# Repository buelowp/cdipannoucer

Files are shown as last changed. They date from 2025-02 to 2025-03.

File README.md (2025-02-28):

# Cobalt Digigal IP turnout control state announcer
The goal of this project is to provide a simple mechanism to report the realtime state of a Cobal Digital IP turnout control motor to loconet. For brevity, Cobalt Digital IP is reduced to CDIP in my work.

## Design
The Cobalt motor is really nice, it's a self contained DCC design and is reasonably robust. Not the quietest, but it works, and it works well with Digitrax and JMRI. However, because it's DCC only, JMRI has no mechanism for requesting state from the motor. This means, at startup, or if something outside of Loconet changes the turnout state, JMRI does not know that it happened. I like it when I see my layout in JMRI in the correct state. I have a 4 turnout cross over and two turnouts which gate reverse loops which are automated

So, basically, I chose this as a low impact HW/SW project I could do to solve the problem. I'm learning how to do HW as a long term software engineer by trade, and enjoy doing small projects with MCU's. This may not be very useful to very many people, but it's fun and I'm looking forward to using it on my layout which has about 30 turnouts in a 19'x19' snaking layout.

This will not do loconet forwarding, and you can't daisy chain. I started to think for the cost, it's pry just smarter to use a UP7 without the faceplate which gives you 4 reliable ports for ~16USD. While adding the HW here would have been cheaper, the cost and complexity made it less interesting to me. I may put it back in later as I get better a loconet circuitry. I removed the daisy chain option, even though that's effectively free, as you can't infinitely chain non boosted devices together, and I didn't want to keep track of how many were connected.

This design makes use of Seeed Studio XIAO modules. I love these things. They are pretty cheap overall, tiny, and you can swap different modules on the same carrier. So, my design uses the Pico MCU because I don't want to include WiFi in my design. My basement layout is pretty far from the nearest router, and I don't want to suck up a lot of the router's attention for these when turned on. However, without changing the hardware, or changing the board size, anyone could use the ESP32 if they choose to. The benefit there might be MQTT and adding a webserver to assign DCC addresses without recompiling the firmware.

While not yet coded up, my mechanism for knowing when to send a startup message will be based on the first Loconet traffic the board sees. As this can be DCC powered, it can also be DC powered, so triggering on when we start to see traffic would be the most beneficial in all cases.

## Requirements
* Provide Loconet messages for turnout state changes as they happen
* Provide a loconet message indicating turnout state on DCC power up
* Handle four turnouts on one board
* Run with either an ESP32 or RPi Pico
* Not require more than 8 GPIO (this one currently only uses 7, three are just there not doing much)
* Wide input voltage range
* Allow for direct connection of indicator LEDs for the turnout.
    * This allows to wire up signals as an example, without the need for extra diodes/resistors along the wire run.

### What it doesn't currently do
* Will not switch the turnout via a Loconet message
* Does not have a second Loconet port for daisy chain

## KiCad design
This is a work in progress. What I've got posted now is version 2, not yet ordered.

I built a first board based solely on a few simple schematic facts hoping they all sort of would just work. This did allow me to test the GPIO portion of the design and validate my assumptions were correct. However, version 1, which is not in git unforunately, did not work for Loconet traffic. I don't know why, but I did make a mistake in the pin assigments for the second Serial port on the XIAO Pico module. I did jumper it, but it still doesn't work. I also didn't add test points, so it's not possible for me at home to use a scope to figure out what's going on. All of those facts are fixed in the current version.

Recently, I also added the ability to use DCC for power. However, I couldn't find a way to combine the two DCC connectors at that point, so you always need a DCC input for the IO, but if you want to power via DCC, then you simply plug a DCC bus into the power connection. For this reason, that connection is no longer polarized, and it doesn't matter which way you wire it.

I also added 3 pins connected to D8, D9, and D10 in Arduino land. They have both Ground and Power pins to go with, so you can use them however you feel the urge. I would limit any GPIO access to 30ma total though, as you have 500ma from the board, but roughly 200ma is already consumed.

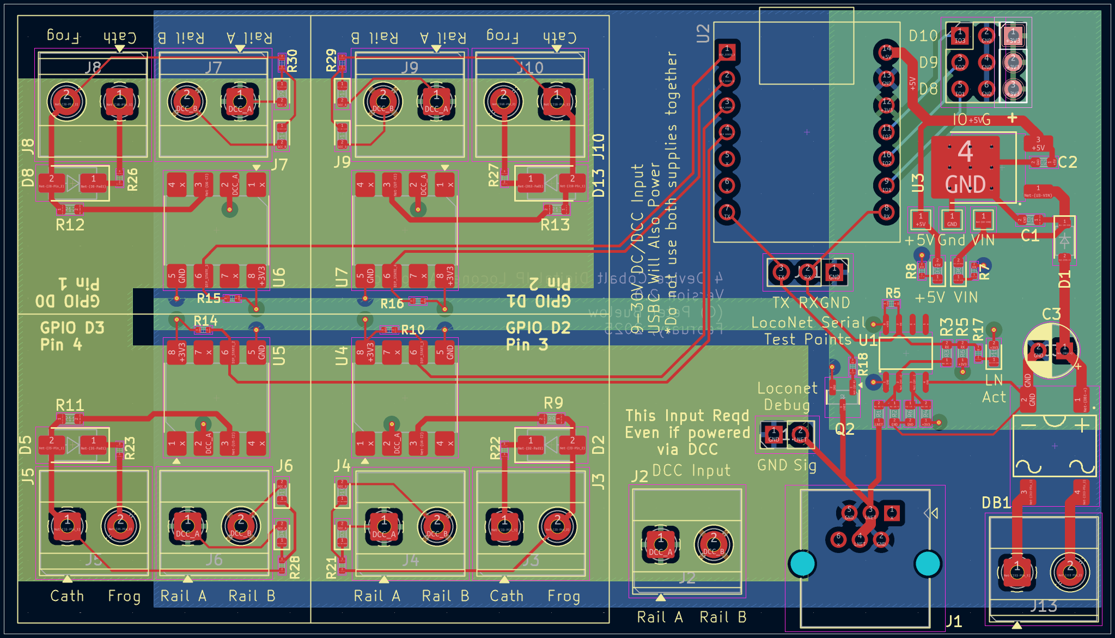
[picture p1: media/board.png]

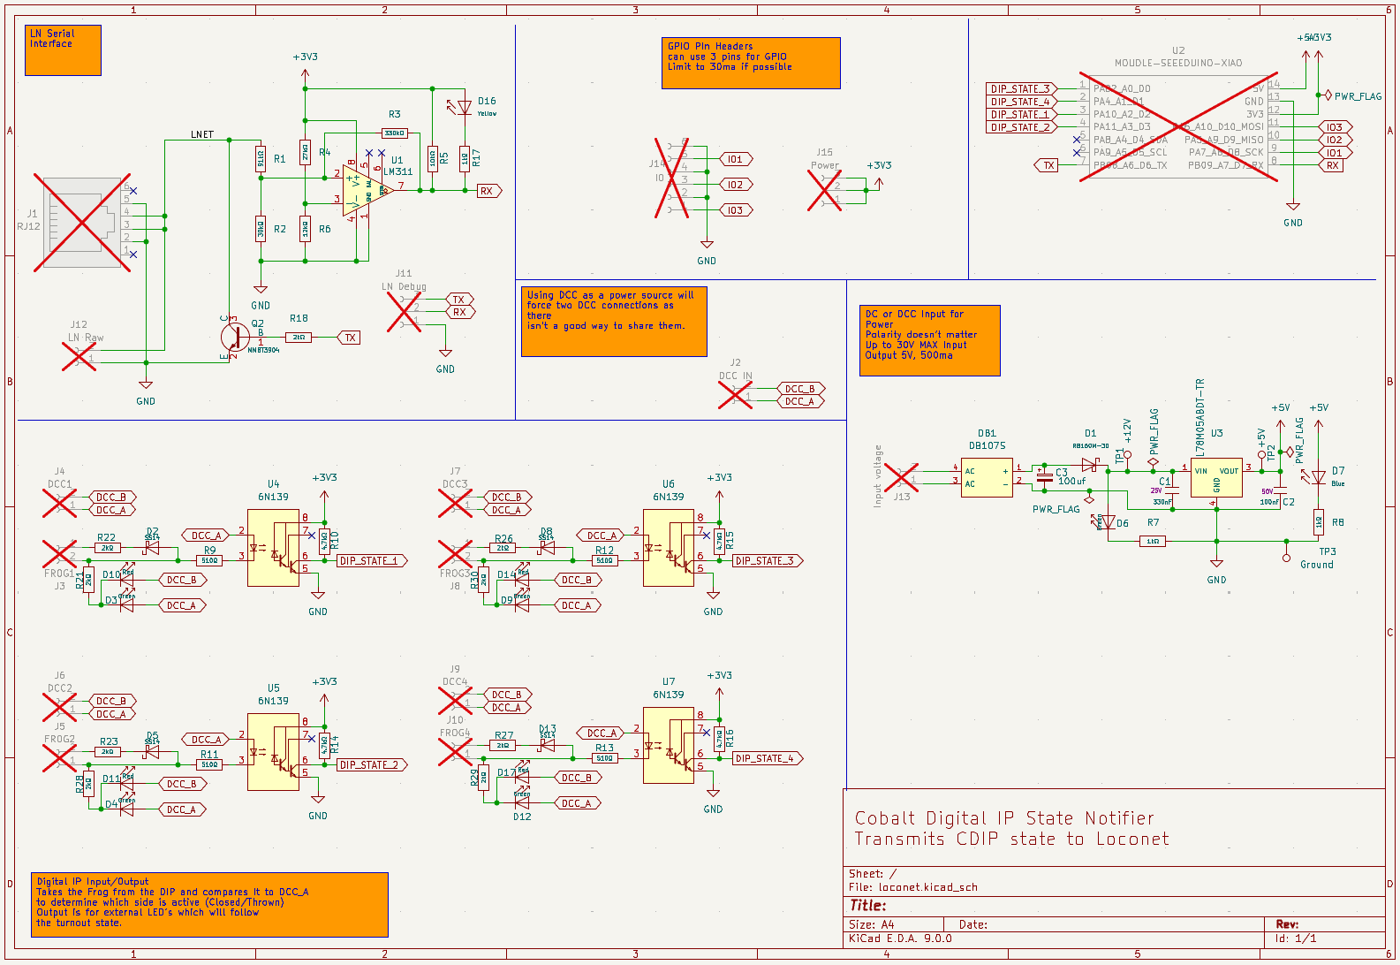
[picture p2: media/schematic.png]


## KiCad notes
This design makes use of JLCPCB to source and order. The parts are identified in the BOM, and the parts that can't be assembled by JLCPCB are marked as such (the red X). I used a plugin to get the parts from

https://github.com/CDFER/JLCPCB-Kicad-Library

Which cannot at this time be installed automatically. Follow the directions on the README.

I also use the JLCPCB Fab extension which can be installed directly from the Extensions dialog.

# Notes
* The orientation of the DCC inputs into the Digital IP does matter. I assume for this device that DCC Rail A as labeled coming out of a Digitrax command station is the outer most pin 1 in the diagram below. If you reverse and put DCC Rail B into that slot, you either have to reverse Rail A and B inputs for the DCC Input terminal or update the code to account for the direction messages being backwards. Note, if you reverse using DCC address 197, you must also reverse the direction. This can be done by setting the CDIP inverted boolean to true.
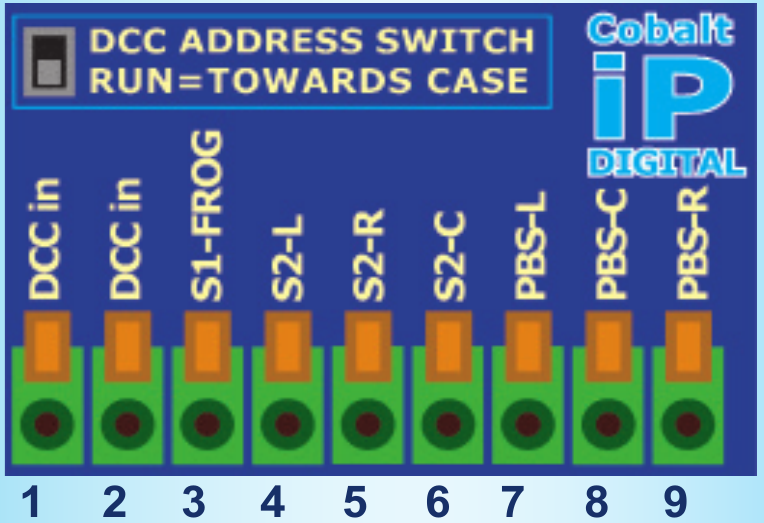
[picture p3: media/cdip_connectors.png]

* This is DC only, but takes up to 30V as input. The reason for this is that I have a 15V DC power bus running with the DCC bus to power some of the Digitrax devices in use (mostly PM74's). For the length of those conductors, even at 16Ga, you get some voltage drop and this should allow the boards to not worry about that.

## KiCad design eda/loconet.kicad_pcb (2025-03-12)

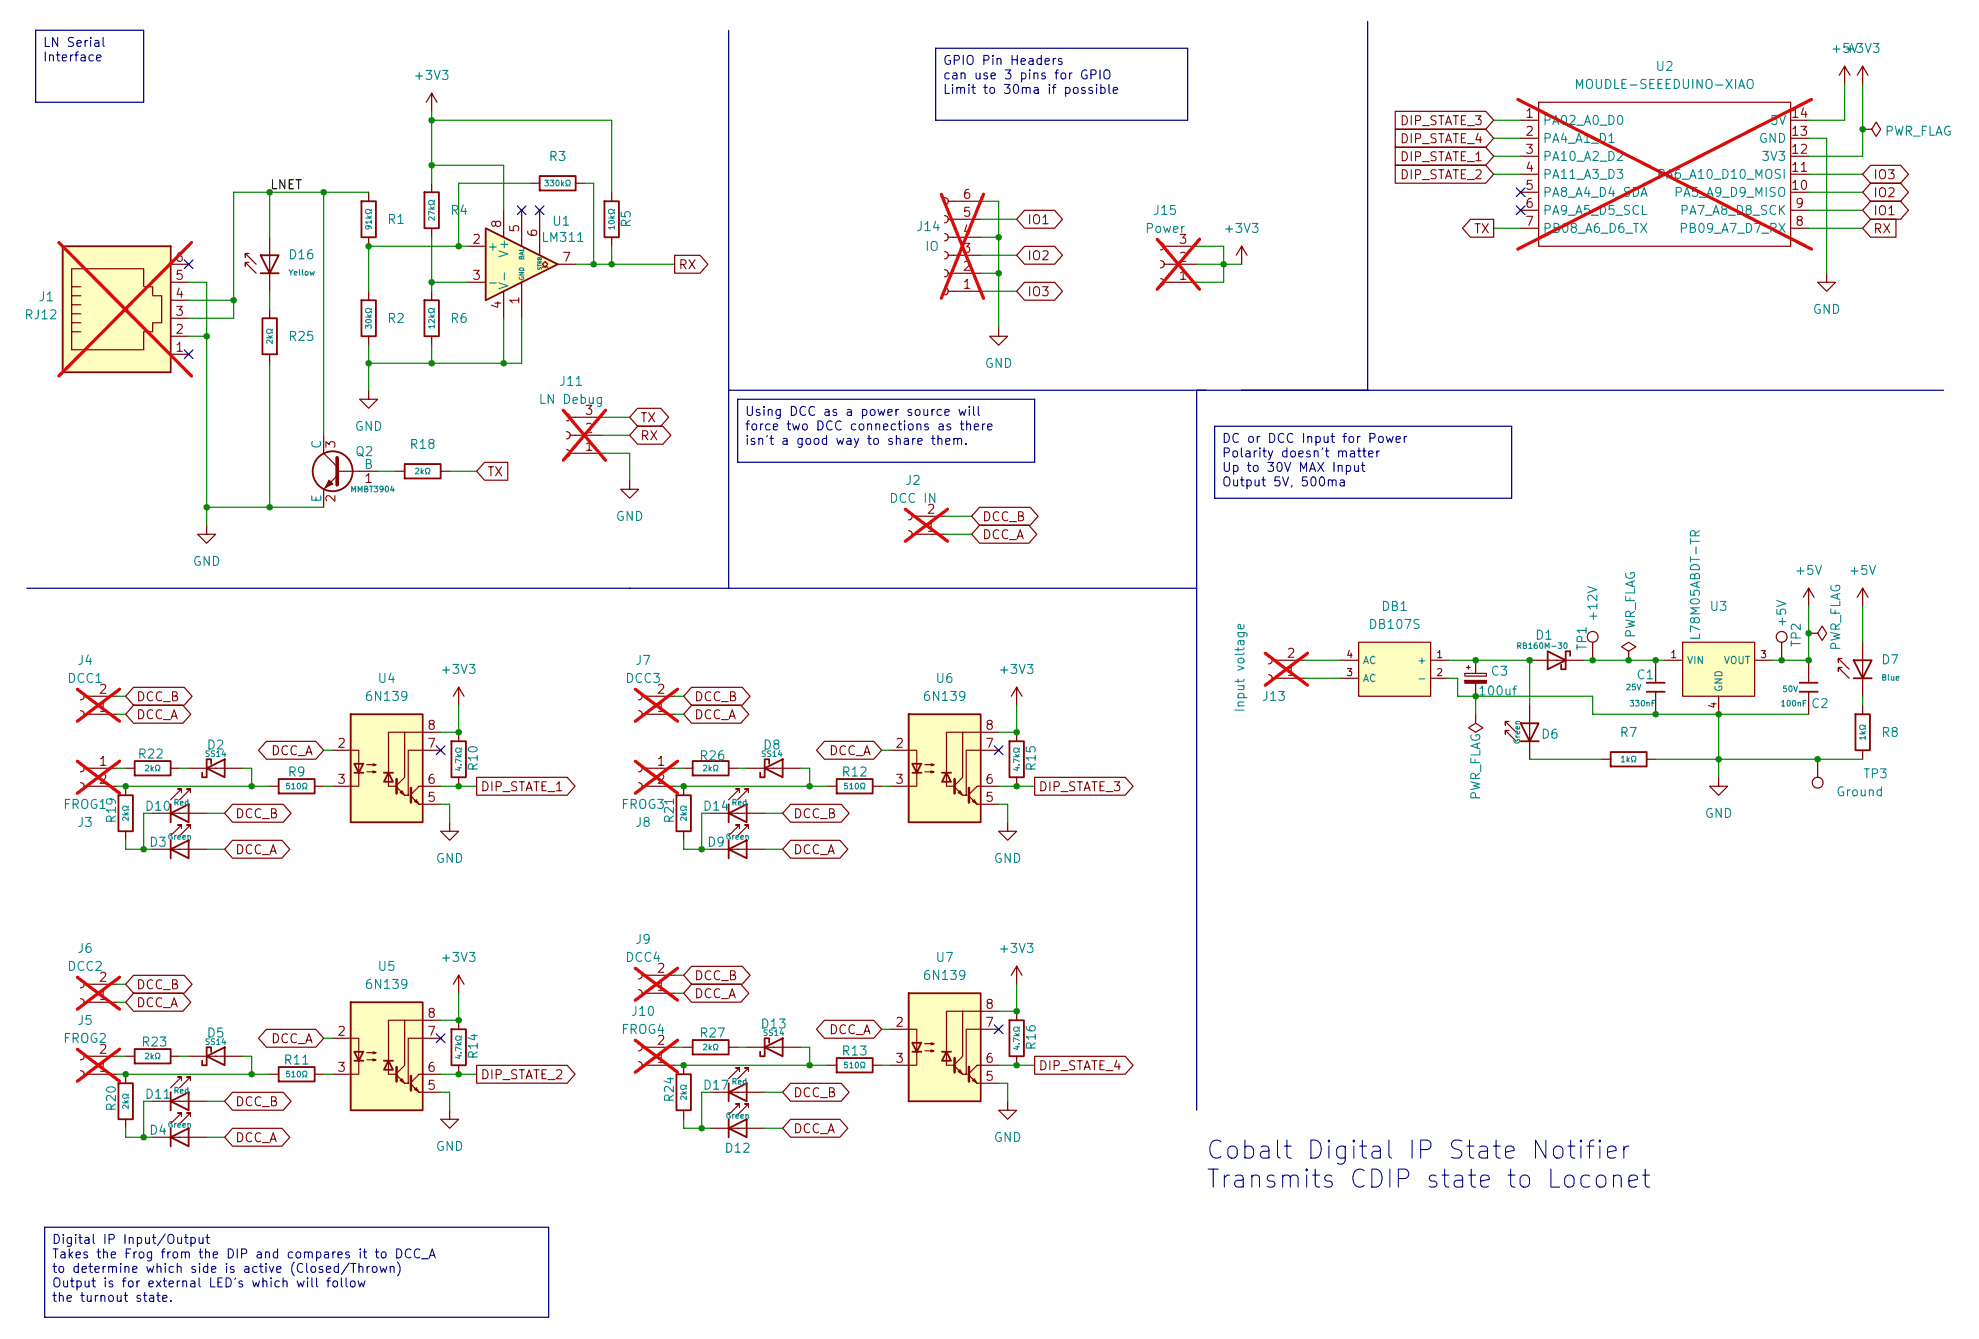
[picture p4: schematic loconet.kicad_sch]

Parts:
C1: 330nF; C_0603; Voltage Rated 25V; Tolerance ±10%; Part 0603B334K250NT; LCSC C1615
C2: 100nF; C_0603; Voltage Rated 50V; Tolerance ±10%; Part CC0603KRX7R9BB104; LCSC C14663
C3: 100uf; CP_Radial_D5.0mm_P2.50mm
D1: RB160M-30; D_SOD-123; Forward Voltage (Vf@If) 480mV@1A; Reverse Voltage (Vr) 30V; Part RB160M-30; LCSC C7502715
D2, D5, D8, D13: SS14; D_SMA; Forward Voltage (Vf@If) 550mV@1A; Reverse Voltage (Vr) 40V; Part SS14; LCSC C2480
D3, D4, D6, D9, D12: Green; D_0603; Part 19-217/GHC-YR1S2/6T; LCSC C2986059
D7: Blue; D_0603; Part 19-217/BHC-ZL1M2RY/6T; LCSC C2986058
D10, D11, D14, D17: Red; D_0603; Part KT-0603R; LCSC C2286
D16: Yellow; D_0603; Part 19-213/Y2C-CQ2R2L/3T(CY); LCSC C72038
DB1: DB107S; DBS_L8.2-W6.4-P5.10-LS10.0-BL; Reverse Voltage (Vr) 1kV; Forward Voltage (Vf@If) 1.1V@1A; Part DB107S; LCSC C5377
J1: RJ12; RJ25_Wayconn_MJEA-660X1_Horizontal; not fitted
J2: DCC IN; TerminalBlock_Phoenix_MKDS-1,5-2-5.08_1x02_P5.08mm_Horizont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; not fitted
J3: FROG1; TerminalBlock_Phoenix_MKDS-1,5-2-5.08_1x02_P5.08mm_Horizont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; not fitted
J4: DCC1; TerminalBlock_Phoenix_MKDS-1,5-2-5.08_1x02_P5.08mm_Horizont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; not fitted
J5: FROG2; TerminalBlock_Phoenix_MKDS-1,5-2-5.08_1x02_P5.08mm_Horizont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; not fitted
J6: DCC2; TerminalBlock_Phoenix_MKDS-1,5-2-5.08_1x02_P5.08mm_Horizont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; not fitted
J7: DCC3; TerminalBlock_Phoenix_MKDS-1,5-2-5.08_1x02_P5.08mm_Horizont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; not fitted
J8: FROG3; TerminalBlock_Phoenix_MKDS-1,5-2-5.08_1x02_P5.08mm_Horizont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; not fitted
J9: DCC4; TerminalBlock_Phoenix_MKDS-1,5-2-5.08_1x02_P5.08mm_Horizont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; not fitted
J10: FROG4; TerminalBlock_Phoenix_MKDS-1,5-2-5.08_1x02_P5.08mm_Horizont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; not fitted
J11: LN Debug; PinHeader_1x03_P2.54mm_Vertical; not fitted
J13: Input voltage; TerminalBlock_Phoenix_MKDS-1,5-2-5.08_1x02_P5.08mm_Horizont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; not fitted
J14: IO; PinHeader_2x03_P2.54mm_Vertical; not fitted
J15: Power; PinHeader_1x03_P2.54mm_Vertical; not fitted
Q2: MMBT3904; Q_SOT-23; Part MMBT3904; LCSC C7420353
R1: 91kΩ; R_0603; Overload Voltage (Max) 75V; Tolerance ±1%; Part 0603WAF9102T5E; LCSC C23265
R2: 30kΩ; R_0603; Overload Voltage (Max) 75V; Tolerance ±1%; Part 0603WAF3002T5E; LCSC C22984
R3: 330kΩ; R_0603; Overload Voltage (Max) 75V; Tolerance ±1%; Part 0603WAF3303T5E; LCSC C23137
R4: 27kΩ; R_0603; Overload Voltage (Max) 75V; Tolerance ±1%; Part 0603WAF2702T5E; LCSC C22967
R5: 10kΩ; R_0603; Overload Voltage (Max) 75V; Tolerance ±1%; Part 0603WAF1002T5E; LCSC C25804
R6: 12kΩ; R_0603; Overload Voltage (Max) 75V; Tolerance ±1%; Part 0603WAF1202T5E; LCSC C22790
R7, R8: 1kΩ; R_0402; Overload Voltage (Max) 50V; Tolerance ±1%; Part 0402WGF1001TCE; LCSC C11702
R9, R11, R12, R13: 510Ω; R_0603; Overload Voltage (Max) 75V; Tolerance ±1%; Part 0603WAF5100T5E; LCSC C23193
R10, R14, R15, R16: 4.7kΩ; R_0402; Overload Voltage (Max) 50V; Tolerance ±1%; Part 0402WGF4701TCE; LCSC C25900
R18, R22, R23, R25, R26, R27: 2kΩ; R_0402; Overload Voltage (Max) 50V; Tolerance ±1%; Part 0402WGF2001TCE; LCSC C4109
R19, R20, R21, R24: 2kΩ; R_0805; Overload Voltage (Max) 150V; Tolerance ±1%; Part 0805W8F2001T5E; LCSC C17604
TP1: +12V; TestPoint_Pad_1.5x1.5mm
TP2: +5V; TestPoint_Pad_1.5x1.5mm
TP3: Ground; TestPoint_Pad_1.5x1.5mm
U1: LM311; SOIC-8_L4.9-W3.9-P1.27-LS6.0-BL; LCSC C231850
U2: MOUDLE-SEEEDUINO-XIAO; MOUDLE14P-2.54-21X17.8MM; not fitted
U3: L78M05ABDT-TR; TO-252-2_L6.5-W6.1-P4.58-LS10.0-TL; Output Voltage 5V; Part L78M05ABDT-TR; LCSC C58069
U4, U5, U6, U7: 6N139; SOP-8_6.605x9.655mm_P2.54mm; LCSC C42186

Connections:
+3V3: J15.1, J15.2, J15.3, R4.1, R5.1, R10.1, R14.1, R15.1, R16.1, U1.8 (V+), U2.12 (3V3), U4.8 (VCC), U5.8 (VCC), U6.8 (VCC), U7.8 (VCC); also elsewhere on the board
+5V: C2.1, D7.2, TP2.1, U2.14 (5V), U3.3 (VOUT)
/LNET: D16.2, J1.3, J1.4, Q2.3 (C), R1.1
DCC_A: D3.2, D4.2, D9.2, D12.2, J2.1, J4.1, J6.1, J7.1, J9.1, U4.2 (C1), U5.2 (C1), U6.2 (C1), U7.2 (C1)
DCC_B: D10.2, D11.2, D14.2, D17.2, J2.2, J4.2, J6.2, J7.2, J9.2
DIP_STATE_1: R10.2, U2.3 (PA10_A2_D2), U4.6 (VO2)
DIP_STATE_2: R14.2, U2.4 (PA11_A3_D3), U5.6 (VO2)
DIP_STATE_3: R15.2, U2.1 (PA02_A0_D0), U6.6 (VO2)
DIP_STATE_4: R16.2, U2.2 (PA4_A1_D1), U7.6 (VO2)
GND: C1.2, C2.2, C3.2, DB1.2 (-), J1.2, J1.5, J11.1, J14.2, J14.4, J14.6, Q2.2 (E), R2.2, R6.2, R7.2, R8.2, R25.1, TP3.1, U1.1 (GND), U1.4 (V-), U2.13 (GND), U3.4 (GND), U4.5 (GND), U5.5 (GND), U6.5 (GND), U7.5 (GND)
IO1: J14.5, U2.9 (PA7_A8_D8_SCK)
IO2: J14.3, U2.10 (PA5_A9_D9_MISO)
IO3: J14.1, U2.11 (PA6_A10_D10_MOSI)
unnamed: D2.1, R22.2
unnamed: D5.1, R23.2
unnamed: D6.1, R7.1
unnamed: D7.1, R8.1
unnamed: D8.1, R26.2
unnamed: D3.1, D10.1, R19.2
unnamed: D4.1, D11.1, R20.2
unnamed: D12.1, D17.1, R24.2
unnamed: D13.1, R27.2
unnamed: D9.1, D14.1, R21.2
unnamed: D16.1, R25.2
unnamed: C3.1, D1.2, D6.2, DB1.1 (+)
unnamed: J3.1, R22.1
unnamed: D2.2, J3.2, R9.1, R19.1
unnamed: D5.2, J5.1, R11.1, R20.1
unnamed: J5.2, R23.1
unnamed: J8.1, R26.1
unnamed: D8.2, J8.2, R12.1, R21.1
unnamed: D13.2, J10.1, R13.1, R24.1
unnamed: J10.2, R27.1
unnamed: DB1.3 (AC), J13.1
unnamed: DB1.4 (AC), J13.2
unnamed: Q2.1 (B), R18.1
unnamed: R1.2, R2.1, R3.1, U1.2 (+)
unnamed: R4.2, R6.1, U1.3 (-)
unnamed: C1.1, D1.1, TP1.1, U3.1 (VIN)
unnamed: R9.2, U4.3 (C2)
unnamed: R11.2, U5.3 (C2)
unnamed: R12.2, U6.3 (C2)
unnamed: R13.2, U7.3 (C2)
RX: J11.2, R3.2, R5.2, U1.7, U2.8 (PB09_A7_D7_RX); also elsewhere on the board
TX: J11.3, R18.2, U2.7 (PB08_A6_D6_TX)

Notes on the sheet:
Cobalt Digital IP State Notifier Transmits CDIP state to Loconet
DC or DCC Input for Power Polarity doesn't matter Up to 30V MAX Input Output 5V, 500ma
Digital IP Input/Output Takes the Frog from the DIP and compares it to DCC_A to determine which side is active (Closed/Thrown) Output is for external LED's which will follow the turnout state.
GPIO Pin Headers can use 3 pins for GPIO Limit to 30ma if possible
LN Serial Interface
Using DCC as a power source will force two DCC connections as there isn't a good way to share them.

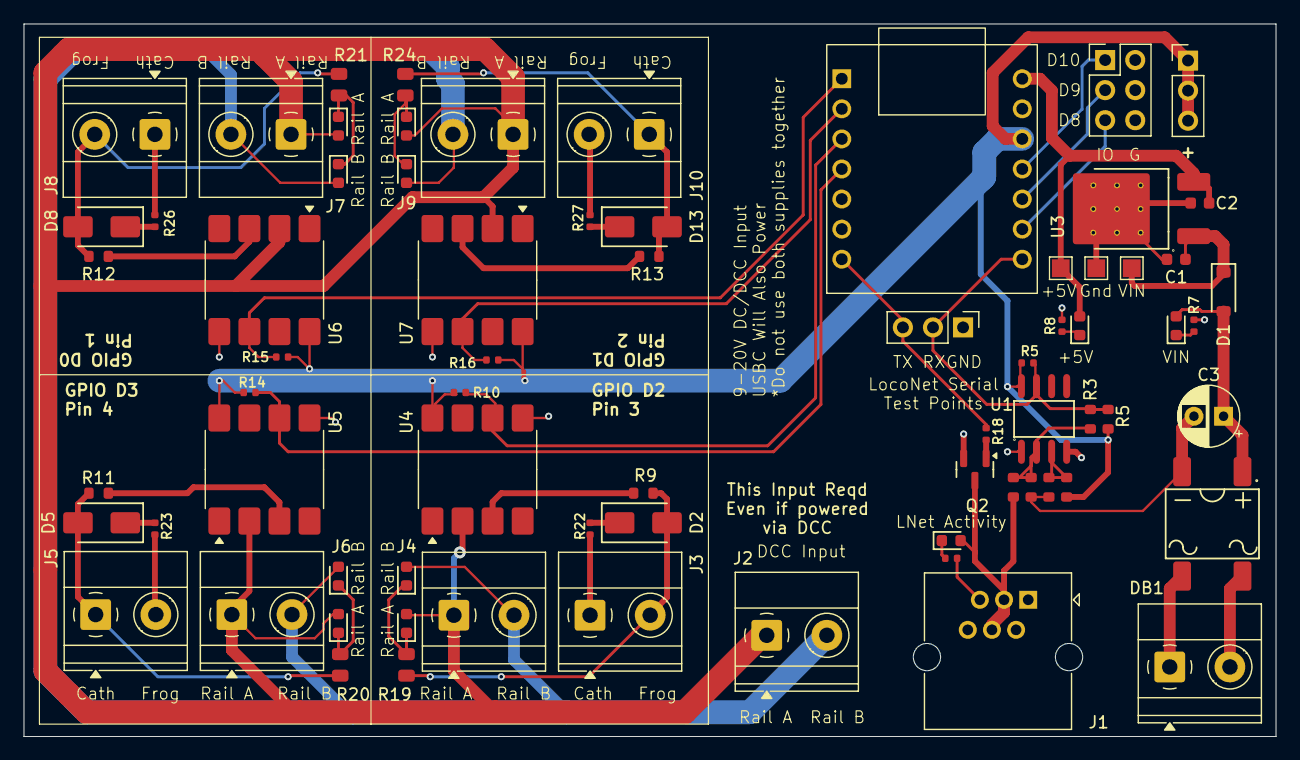
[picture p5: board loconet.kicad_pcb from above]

Board: 2 copper layers, 105.7 x 60.2 mm, 72 parts (0 on the bottom side), 45 nets.

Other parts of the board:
R5#2: 10kΩ; R_0603

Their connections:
+3V3: R5#2.1; also elsewhere on the board
RX: R5#2.2; also elsewhere on the board

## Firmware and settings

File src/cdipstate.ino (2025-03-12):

/*
MIT License

Copyright (c) 2025 Peter Buelow

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
THE SOFTWARE IS PROVIDED "AS IS", WITHOUT WARRANTY OF ANY KIND, EXPRESS OR
IMPLIED, INCLUDING BUT NOT LIMITED TO THE WARRANTIES OF MERCHANTABILITY,
FITNESS FOR A PARTICULAR PURPOSE AND NONINFRINGEMENT. IN NO EVENT SHALL THE
AUTHORS OR COPYRIGHT HOLDERS BE LIABLE FOR ANY CLAIM, DAMAGES OR OTHER
LIABILITY, WHETHER IN AN ACTION OF CONTRACT, TORT OR OTHERWISE, ARISING FROM,
OUT OF OR IN CONNECTION WITH THE SOFTWARE OR THE USE OR OTHER DEALINGS IN THE
SOFTWARE.
*/
#include <LocoNetStreamRP2040.h>
#include "pico/stdlib.h"

#include "cdip.h"

#define LOCONET_PIN_RX  PIN_SERIAL1_RX
#define LOCONET_PIN_TX  PIN_SERIAL1_TX

#define LN_STATUS       PIN_LED_G

#define CDIP_1_GPIO        D0
#define CDIP_2_GPIO        D1
#define CDIP_3_GPIO        D2
#define CDIP_4_GPIO        D3

#define CDIP_1_ADDR         510
#define CDIP_2_ADDR         511
#define CDIP_3_ADDR         500
#define CDIP_4_ADDR         513

#define STATE_CHANGE_TIMEOUT    250

#define VERSION 6

LocoNetBus bus;
LocoNetDispatcher parser(&bus);

CDIP cdip1(true, CDIP_1_ADDR, &bus);
CDIP cdip2(true, CDIP_2_ADDR, &bus);
CDIP cdip3(true, CDIP_3_ADDR, &bus);
CDIP cdip4(true, CDIP_4_ADDR, &bus);

// The line below initialised the LocoNet interface for the correct signal polarity of the IoTT LocoNet Interface board
// See: https://myiott.org/index.php/iott-stick/communication-modules/loconet-interface
LocoNetStreamRP2040 lnStream(&Serial1, LOCONET_PIN_RX, LOCONET_PIN_TX, &bus, false, true);

void cdip1_state(void)
{
    cdip1.active(true);
    cdip1.restartTimer();
}

void cdip2_state(void)
{
    cdip2.active(true);
    cdip2.restartTimer();
}

void cdip3_state(void)
{
    cdip3.active(true);
    cdip3.restartTimer();
}

void cdip4_state(void)
{
    cdip4.active(true);
    cdip4.restartTimer();
}

void setup()
{
    Serial.begin(115200);
    while((!Serial) && (millis() < 5000))
        delay(1);

    lnStream.start();

    parser.onPacket(CALLBACK_FOR_ALL_OPCODES, [](const lnMsg *rxPacket) {
        char tmp[100];
        formatMsg(*rxPacket, tmp, sizeof(tmp));
        Serial.printf("onPacket: %s\n", tmp);
    });

    pinMode(PIN_LED_R, OUTPUT);
    pinMode(PIN_LED_G, OUTPUT);
    pinMode(PIN_LED_B, OUTPUT);

    pinMode(CDIP_1_GPIO, INPUT);
    pinMode(CDIP_2_GPIO, INPUT);
    pinMode(CDIP_3_GPIO, INPUT);
    pinMode(CDIP_4_GPIO, INPUT);

    attachInterrupt(CDIP_1_GPIO, cdip1_state, FALLING);
    attachInterrupt(CDIP_2_GPIO, cdip2_state, FALLING);
    attachInterrupt(CDIP_3_GPIO, cdip3_state, FALLING);
    attachInterrupt(CDIP_4_GPIO, cdip4_state, FALLING);

    digitalWrite(PIN_LED_R, HIGH);
    digitalWrite(PIN_LED_G, HIGH);
    digitalWrite(PIN_LED_B, HIGH);

//    cdip1.start();
//    cdip2.start();
    cdip3.start();
//    cdip4.start();

    Serial.printf("Finished Setup: Version %d\n", VERSION);
}

void loop()
{
    lnStream.process();
}

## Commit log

2025-02-24 Adding the existing files
    * Note, the hardware isn't tested, don't use it yet
    [loconet.kicad_pcb, loconet.kicad_sch]
2025-02-24 Code changes
    * Moved the timer into the class
2025-02-24 Fixups
    * I removed the additional forwarding power part of the LN schematic. I don't think I was doing it right anyway. use a UP5 instead.
    [loconet.kicad_pcb, loconet.kicad_sch]
2025-02-25 Updating to the latest version of the board, still in KiCad 8.
    * Bumped the README to be more readable.
    * Removed second RJ12 jack, no more forwarding.
    * Small changes to the ino.wq
    [loconet.kicad_pcb, loconet.kicad_sch]
2025-02-25 Fixing issues with the layout after moving to KiCad 9
    [loconet.kicad_pcb, loconet.kicad_sch]
2025-02-25 Design fixups
    * LDO was too limited in input voltage, switch to a part with a bigger input voltage
    * Update README
    [loconet.kicad_pcb, loconet.kicad_sch]
2025-02-26 Updates
    * Made it possible to power with DCC. You still need a DCC input for the IO, but you can also drive this with DCC.
    * Added some screen printing for help
    * Added 3 GPIO headers. You can connect them how you want, but they aren't protected, so don't do anything dumb.
    * updated readme
    [loconet.kicad_pcb, loconet.kicad_sch]
2025-02-26 Fixes
    * Bumped the turnout indicator LED resistor to a 125mw 0805 as the 62.5mw was likely going to be too small. This allows some headroom.
    * Updated README.
    [loconet.kicad_pcb, loconet.kicad_sch]
2025-02-28 checkpoint, as this board is too expensive.
    [loconet.kicad_pcb, loconet.kicad_sch]
2025-02-28 Fixes for cost reasons
    * Moved to a 2 layer board to try to make this cheaper
    [loconet.kicad_pcb]
2025-02-28 Remove the barrel cap from the BOM.
    [loconet.kicad_sch]
2025-03-12 Mostly works now, but there is still at least one issue.
    * PCB seems to work just fine for reading inputs, and can communicate with a DCS52
    * Code has been tweaked a bit, and the inverted parameters are weird, but opposites work
    * For whatever reason, when I plug in the USB to DCS52 and connect JMRI, this all goes to hell
    [loconet.kicad_pcb, loconet.kicad_sch]
